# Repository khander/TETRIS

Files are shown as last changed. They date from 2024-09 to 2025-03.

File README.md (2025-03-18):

# TETRIS
 v1.0

This is my first big project. For pictrures check the IMAGES folder there are some pictures and vids for you to understand better the idea.
The whole project is written in C++ by me except the music part which is in the bottom of main file.
If you want to check the schematics you can open the KICAD folder.
Also you can notice that there is no top_btn in the code and in schematics as well as the 4x4 matrix. That is because when I finally soldered the project there was some issues with pins.
So eventually to make the project trully finished it is better to take two shifting registers and put plus on them insted of wiring it directly to the controller. Guess that is just rookie mistake though:)
So if you would like to ask smth about code or schematics or anything else feel free to do it. Also every feedback will be appreciated.

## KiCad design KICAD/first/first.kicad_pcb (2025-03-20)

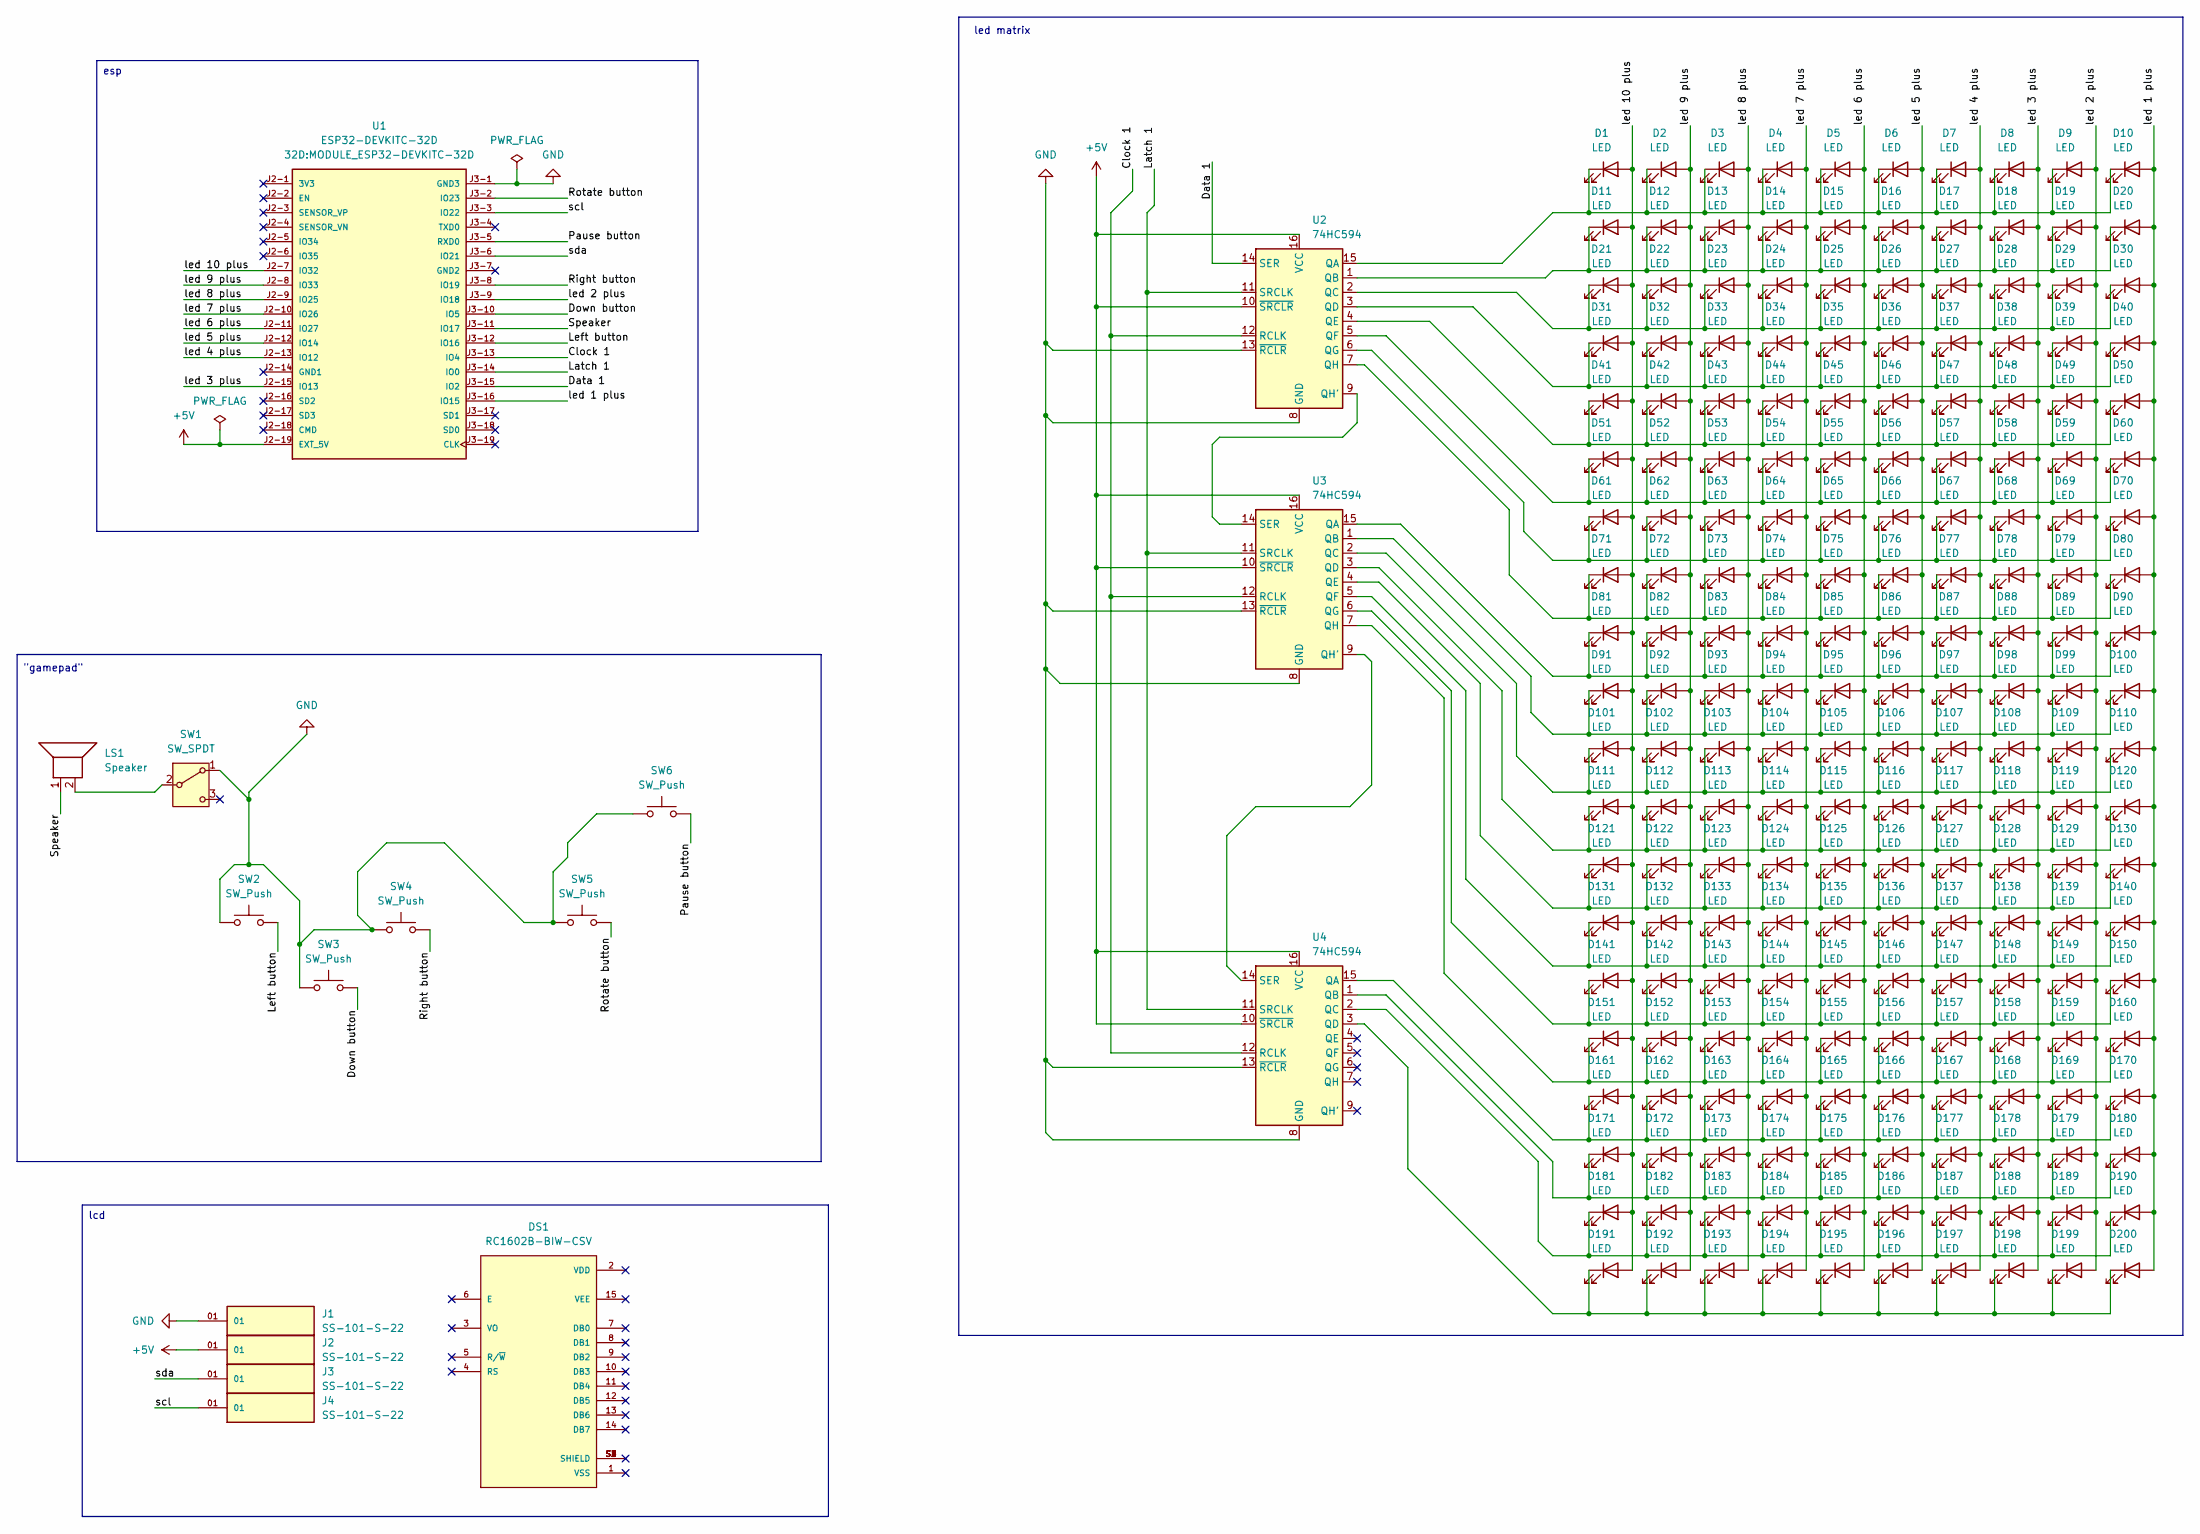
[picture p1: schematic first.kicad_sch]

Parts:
D1, D2, D3, D4, D5, D6, D7, D8, D9, D10, D11, D12, D13, D14, D15, D16, D17, D18, D19, D20, D21, D22, D23, D24, D25, D26, D27, D28, D29, D30, D31, D32, D33, D34, D35, D36, D37, D38, D39, D40, D41, D42, D43, D44, D45, D46, D47, D48, D49, D50, D51, D52, D53, D54, D55, D56, D57, D58, D59, D60, D61, D62, D63, D64, D65, D66, D67, D68, D69, D70, D71, D72, D73, D74, D75, D76, D77, D78, D79, D80, D81, D82, D83, D84, D85, D86, D87, D88, D89, D90, D91, D92, D93, D94, D95, D96, D97, D98, D99, D100, D101, D102, D103, D104, D105, D106, D107, D108, D109, D110, D111, D112, D113, D114, D115, D116, D117, D118, D119, D120, D121, D122, D123, D124, D125, D126, D127, D128, D129, D130, D131, D132, D133, D134, D135, D136, D137, D138, D139, D140, D141, D142, D143, D144, D145, D146, D147, D148, D149, D150, D151, D152, D153, D154, D155, D156, D157, D158, D159, D160, D161, D162, D163, D164, D165, D166, D167, D168, D169, D170, D171, D172, D173, D174, D175, D176, D177, D178, D179, D180, D181, D182, D183, D184, D185, D186, D187, D188, D189, D190, D191, D192, D193, D194, D195, D196, D197, D198, D199, D200: LED; LED_D5.0mm
DS1: RC1602B-BIW-CSV; LCD_RC1602B-BIW-CSV; PARTREV N/A
J1, J2, J3, J4: SS-101-S-22; SAMTEC_SS-101-S-22; PARTREV R
LS1: Speaker; Buzzer_12x9.5RM7.6
SW1: SW_SPDT; SW_Slide-03_Wuerth-WS-SLTV_10x2.5x6.4_P2.54mm
SW2, SW3, SW4, SW5, SW6: SW_Push; SW_PUSH-12mm
U1: ESP32-DEVKITC-32D; MODULE_ESP32-DEVKITC-32D; PARTREV V4
U2, U3, U4: 74HC594; SOIC127P600X175-16N

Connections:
+5V: J2.01, U1.J2-19 (EXT_5V), U2.10 (~SRCLR), U2.16 (VCC), U3.10 (~SRCLR), U3.16 (VCC), U4.10 (~SRCLR), U4.16 (VCC)
/Clock 1: U1.J3-13 (IO4), U2.12 (RCLK), U3.12 (RCLK), U4.12 (RCLK)
/Data 1: U1.J3-15 (IO2), U2.14 (SER)
/Down button: SW3.2, U1.J3-10 (IO5)
/Latch 1: U1.J3-14 (IO0), U2.11 (SRCLK), U3.11 (SRCLK), U4.11 (SRCLK)
/Left button: SW2.2, U1.J3-12 (IO16)
/Pause button: SW6.2, U1.J3-5 (RXD0)
/Right button: SW4.2, U1.J3-8 (IO19)
/Rotate button: SW5.2, U1.J3-2 (IO23)
/Speaker: LS1.1, U1.J3-11 (IO17)
/led 1 plus: D10.2 (A), D20.2 (A), D30.2 (A), D40.2 (A), D50.2 (A), D60.2 (A), D70.2 (A), D80.2 (A), D90.2 (A), D100.2 (A), D110.2 (A), D120.2 (A), D130.2 (A), D140.2 (A), D150.2 (A), D160.2 (A), D170.2 (A), D180.2 (A), D190.2 (A), D200.2 (A), U1.J3-16 (IO15)
/led 2 plus: D9.2 (A), D19.2 (A), D29.2 (A), D39.2 (A), D49.2 (A), D59.2 (A), D69.2 (A), D79.2 (A), D89.2 (A), D99.2 (A), D109.2 (A), D119.2 (A), D129.2 (A), D139.2 (A), D149.2 (A), D159.2 (A), D169.2 (A), D179.2 (A), D189.2 (A), D199.2 (A), U1.J3-9 (IO18)
/led 3 plus: D8.2 (A), D18.2 (A), D28.2 (A), D38.2 (A), D48.2 (A), D58.2 (A), D68.2 (A), D78.2 (A), D88.2 (A), D98.2 (A), D108.2 (A), D118.2 (A), D128.2 (A), D138.2 (A), D148.2 (A), D158.2 (A), D168.2 (A), D178.2 (A), D188.2 (A), D198.2 (A), U1.J2-15 (IO13)
/led 4 plus: D7.2 (A), D17.2 (A), D27.2 (A), D37.2 (A), D47.2 (A), D57.2 (A), D67.2 (A), D77.2 (A), D87.2 (A), D97.2 (A), D107.2 (A), D117.2 (A), D127.2 (A), D137.2 (A), D147.2 (A), D157.2 (A), D167.2 (A), D177.2 (A), D187.2 (A), D197.2 (A), U1.J2-13 (IO12)
/led 5 plus: D6.2 (A), D16.2 (A), D26.2 (A), D36.2 (A), D46.2 (A), D56.2 (A), D66.2 (A), D76.2 (A), D86.2 (A), D96.2 (A), D106.2 (A), D116.2 (A), D126.2 (A), D136.2 (A), D146.2 (A), D156.2 (A), D166.2 (A), D176.2 (A), D186.2 (A), D196.2 (A), U1.J2-12 (IO14)
/led 6 plus: D5.2 (A), D15.2 (A), D25.2 (A), D35.2 (A), D45.2 (A), D55.2 (A), D65.2 (A), D75.2 (A), D85.2 (A), D95.2 (A), D105.2 (A), D115.2 (A), D125.2 (A), D135.2 (A), D145.2 (A), D155.2 (A), D165.2 (A), D175.2 (A), D185.2 (A), D195.2 (A), U1.J2-11 (IO27)
/led 7 plus: D4.2 (A), D14.2 (A), D24.2 (A), D34.2 (A), D44.2 (A), D54.2 (A), D64.2 (A), D74.2 (A), D84.2 (A), D94.2 (A), D104.2 (A), D114.2 (A), D124.2 (A), D134.2 (A), D144.2 (A), D154.2 (A), D164.2 (A), D174.2 (A), D184.2 (A), D194.2 (A), U1.J2-10 (IO26)
/led 8 plus: D3.2 (A), D13.2 (A), D23.2 (A), D33.2 (A), D43.2 (A), D53.2 (A), D63.2 (A), D73.2 (A), D83.2 (A), D93.2 (A), D103.2 (A), D113.2 (A), D123.2 (A), D133.2 (A), D143.2 (A), D153.2 (A), D163.2 (A), D173.2 (A), D183.2 (A), D193.2 (A), U1.J2-9 (IO25)
/led 9 plus: D2.2 (A), D12.2 (A), D22.2 (A), D32.2 (A), D42.2 (A), D52.2 (A), D62.2 (A), D72.2 (A), D82.2 (A), D92.2 (A), D102.2 (A), D112.2 (A), D122.2 (A), D132.2 (A), D142.2 (A), D152.2 (A), D162.2 (A), D172.2 (A), D182.2 (A), D192.2 (A), U1.J2-8 (IO33)
/led 10 plus: D1.2 (A), D11.2 (A), D21.2 (A), D31.2 (A), D41.2 (A), D51.2 (A), D61.2 (A), D71.2 (A), D81.2 (A), D91.2 (A), D101.2 (A), D111.2 (A), D121.2 (A), D131.2 (A), D141.2 (A), D151.2 (A), D161.2 (A), D171.2 (A), D181.2 (A), D191.2 (A), U1.J2-7 (IO32)
/scl: J4.01, U1.J3-3 (IO22)
/sda: J3.01, U1.J3-6 (IO21)
GND: J1.01, SW1.1 (A), SW2.1, SW3.1, SW4.1, SW5.1, SW6.1, U1.J3-1 (GND3), U2.8 (GND), U2.13 (~RCLR), U3.8 (GND), U3.13 (~RCLR), U4.8 (GND), U4.13 (~RCLR)
unnamed: D1.1 (K), D2.1 (K), D3.1 (K), D4.1 (K), D5.1 (K), D6.1 (K), D7.1 (K), D8.1 (K), D9.1 (K), D10.1 (K), U2.15 (QA)
unnamed: D11.1 (K), D12.1 (K), D13.1 (K), D14.1 (K), D15.1 (K), D16.1 (K), D17.1 (K), D18.1 (K), D19.1 (K), D20.1 (K), U2.1 (QB)
unnamed: D21.1 (K), D22.1 (K), D23.1 (K), D24.1 (K), D25.1 (K), D26.1 (K), D27.1 (K), D28.1 (K), D29.1 (K), D30.1 (K), U2.2 (QC)
unnamed: D31.1 (K), D32.1 (K), D33.1 (K), D34.1 (K), D35.1 (K), D36.1 (K), D37.1 (K), D38.1 (K), D39.1 (K), D40.1 (K), U2.3 (QD)
unnamed: D41.1 (K), D42.1 (K), D43.1 (K), D44.1 (K), D45.1 (K), D46.1 (K), D47.1 (K), D48.1 (K), D49.1 (K), D50.1 (K), U2.4 (QE)
unnamed: D51.1 (K), D52.1 (K), D53.1 (K), D54.1 (K), D55.1 (K), D56.1 (K), D57.1 (K), D58.1 (K), D59.1 (K), D60.1 (K), U2.5 (QF)
unnamed: D61.1 (K), D62.1 (K), D63.1 (K), D64.1 (K), D65.1 (K), D66.1 (K), D67.1 (K), D68.1 (K), D69.1 (K), D70.1 (K), U2.6 (QG)
unnamed: D71.1 (K), D72.1 (K), D73.1 (K), D74.1 (K), D75.1 (K), D76.1 (K), D77.1 (K), D78.1 (K), D79.1 (K), D80.1 (K), U2.7 (QH)
unnamed: D81.1 (K), D82.1 (K), D83.1 (K), D84.1 (K), D85.1 (K), D86.1 (K), D87.1 (K), D88.1 (K), D89.1 (K), D90.1 (K), U3.15 (QA)
unnamed: D91.1 (K), D92.1 (K), D93.1 (K), D94.1 (K), D95.1 (K), D96.1 (K), D97.1 (K), D98.1 (K), D99.1 (K), D100.1 (K), U3.1 (QB)
unnamed: D101.1 (K), D102.1 (K), D103.1 (K), D104.1 (K), D105.1 (K), D106.1 (K), D107.1 (K), D108.1 (K), D109.1 (K), D110.1 (K), U3.2 (QC)
unnamed: D111.1 (K), D112.1 (K), D113.1 (K), D114.1 (K), D115.1 (K), D116.1 (K), D117.1 (K), D118.1 (K), D119.1 (K), D120.1 (K), U3.3 (QD)
unnamed: D121.1 (K), D122.1 (K), D123.1 (K), D124.1 (K), D125.1 (K), D126.1 (K), D127.1 (K), D128.1 (K), D129.1 (K), D130.1 (K), U3.4 (QE)
unnamed: D131.1 (K), D132.1 (K), D133.1 (K), D134.1 (K), D135.1 (K), D136.1 (K), D137.1 (K), D138.1 (K), D139.1 (K), D140.1 (K), U3.5 (QF)
unnamed: D141.1 (K), D142.1 (K), D143.1 (K), D144.1 (K), D145.1 (K), D146.1 (K), D147.1 (K), D148.1 (K), D149.1 (K), D150.1 (K), U3.6 (QG)
unnamed: D151.1 (K), D152.1 (K), D153.1 (K), D154.1 (K), D155.1 (K), D156.1 (K), D157.1 (K), D158.1 (K), D159.1 (K), D160.1 (K), U3.7 (QH)
unnamed: D161.1 (K), D162.1 (K), D163.1 (K), D164.1 (K), D165.1 (K), D166.1 (K), D167.1 (K), D168.1 (K), D169.1 (K), D170.1 (K), U4.15 (QA)
unnamed: D171.1 (K), D172.1 (K), D173.1 (K), D174.1 (K), D175.1 (K), D176.1 (K), D177.1 (K), D178.1 (K), D179.1 (K), D180.1 (K), U4.1 (QB)
unnamed: D181.1 (K), D182.1 (K), D183.1 (K), D184.1 (K), D185.1 (K), D186.1 (K), D187.1 (K), D188.1 (K), D189.1 (K), D190.1 (K), U4.2 (QC)
unnamed: D191.1 (K), D192.1 (K), D193.1 (K), D194.1 (K), D195.1 (K), D196.1 (K), D197.1 (K), D198.1 (K), D199.1 (K), D200.1 (K), U4.3 (QD)
unnamed: LS1.2, SW1.2 (B)
unnamed: U2.9 (QH'), U3.14 (SER)
unnamed: U3.9 (QH'), U4.14 (SER)

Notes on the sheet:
lcd
esp
led matrix
"gamepad"

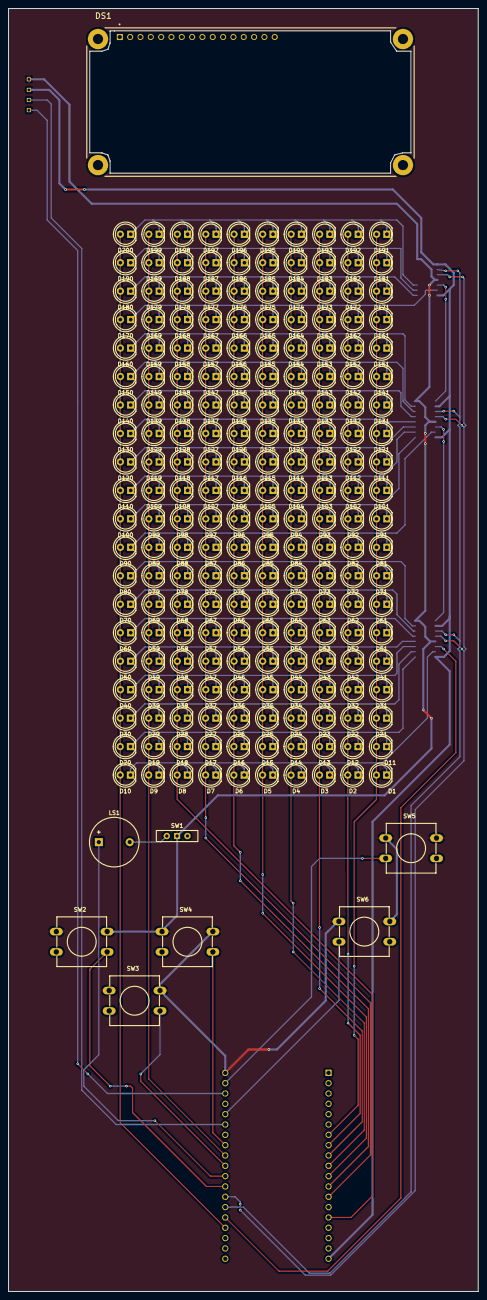
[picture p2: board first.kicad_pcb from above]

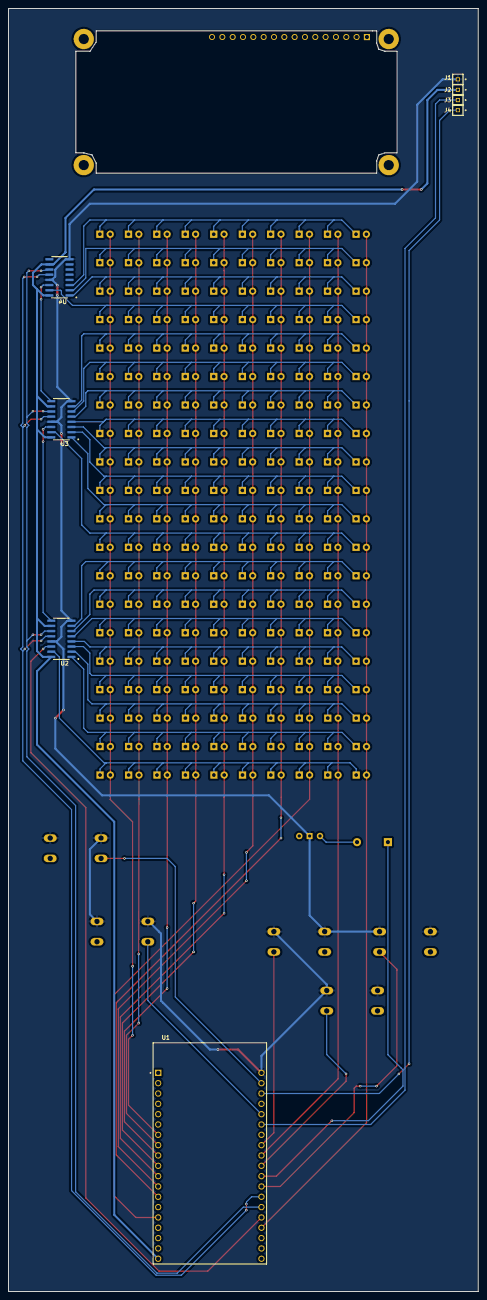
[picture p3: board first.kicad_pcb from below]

Board: 2 copper layers, 115.5 x 315.5 mm, 216 parts (8 on the bottom side), 46 nets.

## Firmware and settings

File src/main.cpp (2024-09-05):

#include "includes.h"

TaskHandle_t Task1;

void Task1code( void * pvParameters );

LiquidCrystal_I2C lcd(0x27, 16, 2);

unsigned long high_score;
unsigned long score;
unsigned int level;
unsigned int levels_cleared;

int current_tick_rate;


Figure *random_figure();

Matrix m;
Figure *fig = random_figure();

void hello_page(){
    lcd.clear();              // clear display
    lcd.setCursor(0, 0);      // move cursor to   (0, 0)
    lcd.print("TETRIS BY");
    lcd.setCursor(0, 1);
    lcd.print("KHANDER");
    usleep(1000000);
    lcd.clear();
    lcd.setCursor(2,0);
    lcd.print("PRESS START");
    lcd.setCursor(5,1);
    lcd.print("BUTTON");
}
   
void pause_page(){
    lcd.clear();
    lcd.setCursor(5, 0);
    lcd.print("PAUSE");
}

void game_over_page(){
    lcd.clear();
    lcd.setCursor(3, 0);
    lcd.print("GAME OVER");
    lcd.setCursor(0, 1);
    lcd.print("SCORE:");
    lcd.print(score);
    usleep(3000000);
    lcd.setCursor(0, 0);
    lcd.print("             ");
    lcd.setCursor(0, 0);
    lcd.print("H_SCORE:");
    lcd.print(high_score);

}

void score_page(){
    lcd.clear();
    lcd.setCursor(0, 0);
    lcd.print("SCORE:");
    lcd.print(score);
    lcd.setCursor(0, 1);
    lcd.print("LVL:");
    lcd.print(level);
}

int lastStatePause = HIGH;
int currentStatePause;
unsigned long lastCheckedTimePause = 0;

void start_btn(){
    while(true){
        currentStatePause = digitalRead(PAUSEBTN);
        if(lastStatePause == LOW && currentStatePause == HIGH) {
            lastStatePause = currentStatePause;
            return;
        }
            
        lastStatePause = currentStatePause;
    }
}

void pause_btn(Matrix& m){
    currentStatePause = digitalRead(PAUSEBTN);

    if(lastStatePause == LOW && currentStatePause == HIGH ){
       
        lastStatePause = currentStatePause;
        pause_page();
        while(true){
            m.print();
            
            currentStatePause = digitalRead(PAUSEBTN);
            if(lastStatePause == LOW && currentStatePause == HIGH) {
                lastCheckedTimePause = millis();
                lastStatePause = currentStatePause;
                score_page();
                return;
            }
            lastStatePause = currentStatePause;

        }
    }
    lastStatePause = currentStatePause;
    
}

void setup() {


    xTaskCreatePinnedToCore(
                    Task1code,   /* Task function. */
                    "Task1",     /* name of task. */
                    10000,       /* Stack size of task */
                    NULL,        /* parameter of the task */
                    1,           /* priority of the task */
                    &Task1,      /* Task handle to keep track of created task */
                    0);          /* pin task to core 0 */       



    pinMode( LEFTBTN, INPUT_PULLUP);
    pinMode( RIGHTBTN, INPUT_PULLUP);
    pinMode( ROTATEBTN, INPUT_PULLUP);
    pinMode( DOWNBTN, INPUT_PULLUP);
    pinMode( PAUSEBTN, INPUT_PULLUP);

    EEPROM.begin(EEPROM_SIZE);
   // EEPROM.writeULong(0, 0);
    high_score = EEPROM.readULong(0);
    level = 0;
    score = 0;
    levels_cleared = 0;
    current_tick_rate = TICKRATE_LEVEL_BASE;
    
    lcd.init();
    lcd.backlight();
    hello_page();
    start_btn();
    score_page();
    
    fig->put_figure(m, 1);

}   //setup

Figure *random_figure(){
    int seed = esp_random() % 7;
    Figure *figure;
    switch(seed){
        case 1:
            figure = new j_figure();
            break;
        case 2:
            figure = new l_figure();
            break;
        case 3:
            figure = new t_figure();
            break;    
        case 4:
            figure = new s_figure();
            break;
        case 5:
            figure = new z_figure();
            break;
        case 6:
            figure = new o_figure();
            break;
        case 0:
            figure = new i_figure();
            break;    
    }
    return figure;
}


int lastStateRight = HIGH;
int currentStateRight;
unsigned long lastCheckedTimeRight = 0;
bool isChangedRight = 0;

void rightButton(){
    currentStateRight = digitalRead(RIGHTBTN);
    fig->put_figure(m, 0);
    
    if(lastStateRight == HIGH && currentStateRight == LOW){
        fig->right(m);
        
        lastCheckedTimeRight = millis();
        isChangedRight = 0;
    }
    else if(lastStateRight == LOW && currentStateRight == HIGH){
        isChangedRight = 1;
       
    }
    lastStateRight = currentStateRight;

    if(currentStateRight == LOW && isChangedRight == 0 && ((millis() - lastCheckedTimeRight) > BOUNCE_TIME)){
        fig->right(m);
        lastCheckedTimeRight = millis();
    }
    fig->put_figure(m, 1);
}

int lastStateLeft = HIGH;
int currentStateLeft;
unsigned long lastCheckedTimeLeft = 0;
bool isChangedLeft = 0;

void leftButton(){
    currentStateLeft = digitalRead(LEFTBTN);
    fig->put_figure(m, 0);
    
    if(lastStateLeft == HIGH && currentStateLeft == LOW){
        fig->left(m);
        
        lastCheckedTimeLeft = millis();
        isChangedLeft = 0;
    }
    else if(lastStateLeft == LOW && currentStateLeft == HIGH){
        isChangedLeft = 1;
       
    }
    lastStateLeft = currentStateLeft;

    if(currentStateLeft == LOW && isChangedLeft == 0 && ((millis() - lastCheckedTimeLeft) > BOUNCE_TIME)){
        fig->left(m);
        lastCheckedTimeLeft = millis();
    }
    fig->put_figure(m, 1);
}

int lastStateDown = HIGH;
int currentStateDown;
unsigned long lastCheckedTimeDown = 0;
bool isChangedDown = 0;

void downButton(){
    currentStateDown = digitalRead(DOWNBTN);
    fig->put_figure(m, 0);
    
    if(lastStateDown == HIGH && currentStateDown == LOW){
        fig->down(m);
        score++;            //1 point for each skipped row
        lastCheckedTimeDown = millis();
        isChangedDown = 0;
    }
    else if(lastStateDown == LOW && currentStateDown == HIGH){
        isChangedDown = 1;
       
    }
    lastStateDown = currentStateDown;

    if(currentStateDown == LOW && isChangedDown == 0 && ((millis() - lastCheckedTimeDown) > BOUNCE_TIME_DOWN)){
        fig->down(m);
        score++;         //1 point for each skipped row
        lastCheckedTimeDown = millis();
    }
    fig->put_figure(m, 1);
}

int lastStateRotate = HIGH;
int currentStateRotate;
unsigned long lastCheckedTimeRotate = 0;
bool isChangedRotate = 0;

void rotateButton(){
    currentStateRotate = digitalRead(ROTATEBTN);
    fig->put_figure(m, 0);
    
    if(lastStateRotate == HIGH && currentStateRotate == LOW){
        fig->rotate(m);
        
        lastCheckedTimeRotate = millis();
        isChangedRotate = 0;
    }
    else if(lastStateRotate == LOW && currentStateRotate == HIGH){
        isChangedRotate = 1;
       
    }
    lastStateRotate = currentStateRotate;

    if(currentStateRotate == LOW && isChangedRotate == 0 && ((millis() - lastCheckedTimeRotate) > BOUNCE_TIME)){
        fig->rotate(m);
        lastCheckedTimeRotate = millis();
    }
    fig->put_figure(m, 1);
}


static int ticks = 0;
int l = 0;
int r = 0;

void game_over(){
    if(score > high_score){
        high_score = score;
        EEPROM.writeULong(0, high_score);
        EEPROM.commit();
    }
    game_over_page();

    score = 0;
    level = 0;
    levels_cleared = 0;
    start_btn();
    m.reset_matrix();

    
}

void points_to_add(int rows_points){
    int temp_score = 0;
    switch(rows_points){
        case 1: 
            temp_score = 40;
            break;
        case 2:
            temp_score = 100;
            break;
        case 3:
            temp_score = 300;
            break;
        case 4:
            temp_score = 1200;
            break;
        default:
            break;
    }
    temp_score *=(level + 1);
    score += temp_score;
    levels_cleared+=rows_points;
    if(levels_cleared >=10){
        level++;
        levels_cleared -=10;
    }
}

void loop() {
    
    
    
    m.print();
    ticks++;
    
    rightButton();
    leftButton();
    rotateButton();
    downButton();
    pause_btn(m);

    if(ticks == current_tick_rate){

        fig->put_figure(m, 0);
        if(!(fig->down(m))){
            fig->put_figure(m, 1);
            int rows_points = m.check_rows_to_delete();
            if(rows_points > 0){
                m.delete_chosen_rows();
                points_to_add(rows_points);
                if(level >= 13 && level < 16){
                    current_tick_rate = TICKRATE_LEVEL_1;
                }
                else if(level >= 16 && level < 19){
                    current_tick_rate = TICKRATE_LEVEL_2;
                }
                else if(level >= 19 && level < 29){
                    current_tick_rate = TICKRATE_LEVEL_3;
                }
                else if(level >= 29){
                    current_tick_rate = TICKRATE_LEVEL_KILLZONE;
                }
                else{
                    current_tick_rate = TICKRATE_LEVEL_BASE - level * 2;
                }
            }
            score_page();
            if(fig->is_game_over())
                game_over();
            delete fig;
            
            fig = random_figure();
        }
        fig->put_figure(m, 1); 
        ticks = 0;      
    }
    
}   //loop


void Task1code( void * pvParameters ){              //music function


    //author:https://github.com/robsoncouto/arduino-songs/blob/master/tetris/tetris.ino


  // change this to make the song slower or faster
int tempo=144; 

// change this to whichever pin you want to use
int buzzer = SPEAKER;

// notes of the moledy followed by the duration.
// a 4 means a quarter note, 8 an eighteenth , 16 sixteenth, so on
// !!negative numbers are used to represent dotted notes,
// so -4 means a dotted quarter note, that is, a quarter plus an eighteenth!!
int melody[] = {

  //Based on the arrangement at https://www.flutetunes.com/tunes.php?id=192
  
  NOTE_E5, 4,  NOTE_B4,8,  NOTE_C5,8,  NOTE_D5,4,  NOTE_C5,8,  NOTE_B4,8,
  NOTE_A4, 4,  NOTE_A4,8,  NOTE_C5,8,  NOTE_E5,4,  NOTE_D5,8,  NOTE_C5,8,
  NOTE_B4, -4,  NOTE_C5,8,  NOTE_D5,4,  NOTE_E5,4,
  NOTE_C5, 4,  NOTE_A4,4,  NOTE_A4,8,  NOTE_A4,4,  NOTE_B4,8,  NOTE_C5,8,

  NOTE_D5, -4,  NOTE_F5,8,  NOTE_A5,4,  NOTE_G5,8,  NOTE_F5,8,
  NOTE_E5, -4,  NOTE_C5,8,  NOTE_E5,4,  NOTE_D5,8,  NOTE_C5,8,
  NOTE_B4, 4,  NOTE_B4,8,  NOTE_C5,8,  NOTE_D5,4,  NOTE_E5,4,
  NOTE_C5, 4,  NOTE_A4,4,  NOTE_A4,4, REST, 4,

  NOTE_E5, 4,  NOTE_B4,8,  NOTE_C5,8,  NOTE_D5,4,  NOTE_C5,8,  NOTE_B4,8,
  NOTE_A4, 4,  NOTE_A4,8,  NOTE_C5,8,  NOTE_E5,4,  NOTE_D5,8,  NOTE_C5,8,
  NOTE_B4, -4,  NOTE_C5,8,  NOTE_D5,4,  NOTE_E5,4,
  NOTE_C5, 4,  NOTE_A4,4,  NOTE_A4,8,  NOTE_A4,4,  NOTE_B4,8,  NOTE_C5,8,

  NOTE_D5, -4,  NOTE_F5,8,  NOTE_A5,4,  NOTE_G5,8,  NOTE_F5,8,
  NOTE_E5, -4,  NOTE_C5,8,  NOTE_E5,4,  NOTE_D5,8,  NOTE_C5,8,
  NOTE_B4, 4,  NOTE_B4,8,  NOTE_C5,8,  NOTE_D5,4,  NOTE_E5,4,
  NOTE_C5, 4,  NOTE_A4,4,  NOTE_A4,4, REST, 4,
  

  NOTE_E5,2,  NOTE_C5,2,
  NOTE_D5,2,   NOTE_B4,2,
  NOTE_C5,2,   NOTE_A4,2,
  NOTE_GS4,2,  NOTE_B4,4,  REST,8, 
  NOTE_E5,2,   NOTE_C5,2,
  NOTE_D5,2,   NOTE_B4,2,
  NOTE_C5,4,   NOTE_E5,4,  NOTE_A5,2,
  NOTE_GS5,2,

};

// sizeof gives the number of bytes, each int value is composed of two bytes (16 bits)
// there are two values per note (pitch and duration), so for each note there are four bytes
int notes=sizeof(melody)/sizeof(melody[0])/2; 

// this calculates the duration of a whole note in ms (60s/tempo)*4 beats
int wholenote = (60000 * 4) / tempo;

int divider = 0, noteDuration = 0;

  for(;;){
    for (int thisNote = 0; thisNote < notes * 2; thisNote = thisNote + 2) {

    // calculates the duration of each note
    divider = melody[thisNote + 1];
    if (divider > 0) {
      // regular note, just proceed
      noteDuration = (wholenote) / divider;
    } else if (divider < 0) {
      // dotted notes are represented with negative durations!!
      noteDuration = (wholenote) / abs(divider);
      noteDuration *= 1.5; // increases the duration in half for dotted notes
    }

    // we only play the note for 90% of the duration, leaving 10% as a pause
    tone(buzzer, melody[thisNote], noteDuration*0.9);

    // Wait for the specief duration before playing the next note.
    delay(noteDuration);
    
    // stop the waveform generation before the next note.
    noTone(buzzer);
  }
  } 
}

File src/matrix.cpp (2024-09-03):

#include "includes.h"
#include "matrix.h"


int rows[] = {15, 18, 13, 12, 14, 27, 26, 25, 33, 32}; 
 

void _shiftOut(uint8_t dataPin, uint8_t clockPin, uint8_t bitOrder, uint32_t val) {
    uint32_t i;

    for(i = 0; i < 24; i++) {
        if(bitOrder == LSBFIRST)
            digitalWrite(dataPin, !!(val & (1 << i)));
        else
            digitalWrite(dataPin, !!(val & (1 << (7 - i))));

        digitalWrite(clockPin, HIGH);
        digitalWrite(clockPin, LOW);
    }
}   //_shiftOut

Matrix::Matrix(){
    
    pinMode(DATAPIN1, OUTPUT);
    pinMode(LATCHPIN1, OUTPUT);
    pinMode(CLOCKPIN1, OUTPUT);

  for (int i = 0; i < 20; i++){
    for (int j = 0; j < 10; j++){
      matrix[i][j] = 0;
    }
  }
  integer = 0b1;
  for (int i = 0; i < 24; i++){
    integer = integer << 1;
    integer++;
  }
  row = rows;
  for (int i = 0; i < 10; i++){
      pinMode(row[i], OUTPUT);
  }

    for(int i = 0; i < 4; i++)      //array to delete init
        array_to_delete[i] = 0;
    rows_to_clear = 0;

}; // matrix::matrix

void Matrix::reset_matrix(){
    for (int i = 0; i < 25; i++){
    for (int j = 0; j < 10; j++){
      matrix[i][j] = 0;
    }
  }
}   //matrex::reset_matrix

int Matrix::get_state_by_pos(int x, int y){
    y += 4;
    return matrix[y][x];
}   //matrix::get_state_by_pos

void Matrix::print(){
    int integ_copy = integer;
    for (int i = 0; i <= 24 ; i++){
        print_plus(matrix[i]);
        usleep(500);            //for correct output
        print_ground(integer - (1 << i));
  }
}   //matrix::print

void Matrix::print_plus(int* x){
    for (int i = 0; i < 10; i++){
        digitalWrite(row[i], x[i] == 1 ? HIGH : LOW);
        //usleep(10);
    }
}   //print_plus

void Matrix::print_ground(uint32_t x){
    digitalWrite(LATCHPIN1, LOW);
    _shiftOut(DATAPIN1, CLOCKPIN1, LSBFIRST, x);
    digitalWrite(LATCHPIN1, HIGH);
}   //print_ground

int Matrix::set_by_pos(int y, int x, int num){
    y += 4;
    if(y > 24 || y < 0 || x < 0 || x > 9 )
        return -1;
    matrix[y][x] = num > 0 ? 1 : 0;
    return 1;
}   //matrix::set_by_pos

int Matrix::check_rows_to_delete(){
    int counter_array = 0;
    for(int i = 3; i < 25; i++){
        int counter_of_row = 0;
        for(int j = 0; j < 10; j++){
            if(matrix[i][j] == 1)
                counter_of_row++;
            else   
                break;
        }
        if(counter_of_row == 10){       //not neccessary
            array_to_delete[counter_array++] = i;
        }
        rows_to_clear = counter_array;

    }
    return rows_to_clear;
}   //matrix::check_rows_to_delete

void Matrix::delete_chosen_rows(){
    int counter = 1;
    for(int i = 5; i < 10; i++){
        for(int j = 0; j < 4; j++){
            matrix[array_to_delete[j]][i] = 0;
            matrix[array_to_delete[j]][i-counter] = 0;
        }
        counter+=2;
        for(int m = 0; m < 8; m++){     //for normal output
            print();
        }
    }
    for(int i = 0; i < 4; i++){
        if(array_to_delete[i] != 0){
            for(int j = 0; j < 10; j++){
                for(int m = array_to_delete[i]; m > 3; m--){
                    matrix[m][j] = matrix[m-1][j];
                }  
            }
        }
    }
    for(int i = 0; i < 4; i++)      //array to delete init
        array_to_delete[i] = 0;

        //add score
    rows_to_clear = 0;
}   //matrix::delete_chosen_rows

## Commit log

2024-06-15 rotate, left, right moves with buttons and special tickrate
2024-08-22 soldering finished
2024-08-22 fixed: -figures getting out of visible matrix at the edges after rotating -i_figure became 3 parts(not 4) after rotating -figures layering on the figures put in matrix while moving to left/right
    [main.cpp]
2024-08-24 correct buttons output with long press to do: fix the bug with down button
    [main.cpp]
2024-08-24 correct buttons long press fix: down button bug
    [main.cpp]
2024-08-30 bug fixed: down button
    [main.cpp]
2024-09-01 random figues fall increased down button speed while pressed to do: score and level system
2024-09-01 lcd bagan: hello page start(pause) button added
2024-09-04 correct score counting level difficulty managed
    [main.cpp]
2024-09-05 final commit fixed some minor bugs added KiCad schematic README file will be added soon v1.0 - RELEASED :)
    [first.kicad_sch]
2025-03-18 kicad schematic changed. pcb creation started
    led matrix done, some registers wired
    [first.kicad_pcb, first.kicad_sch]
2025-03-20 pcb finished
    add some holes for case to be attached
    [first.kicad_pcb]
